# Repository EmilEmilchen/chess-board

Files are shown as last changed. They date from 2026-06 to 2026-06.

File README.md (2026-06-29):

# Digital RFID-reading Chess Board

## BOMs
BOM files from suppliers are in their respective directories, DigiKey is strongly preferred, LCSC part numbers of equal or equivalent parts are given in the KiCad Symbol Table (aka. KiCad BOM) in case of using JLCPCB assembly services later.
The KiCad generated BOM file is in the root (BOM.csv).
Here is a [link to the BOM on the DigiKey website](https://www.digikey.de/de/mylists/list/6JU4LPDGX9).
Note that 4 (2x2) connectors are to be ordered from amazon or eBay since thats not only cheaper but also simpler (these are still referenced in the DigiKey BOM but not connected to any DigiKey part, same goes for the MFRC522 RFID main IC, that's about 5-10x cheaper when ordered from AliExpress (around 0.47€/pcs).
The materials in the BOM are for one sub-board (2x2 matrix of RFID readers) with a slight excess in some cases where it was cheaper to order e.g. 10 pcs instead of 8 due to bulk discounts.

### Note
The entire chess board will be made up of 16x the same 2x2 matrix circuit (around 80 USD total expected cost).

## KiCad
Use KiCad Version 10 or newer to open the .kicad_pro file, libraries are in the libs/ folder and should automatically be used.

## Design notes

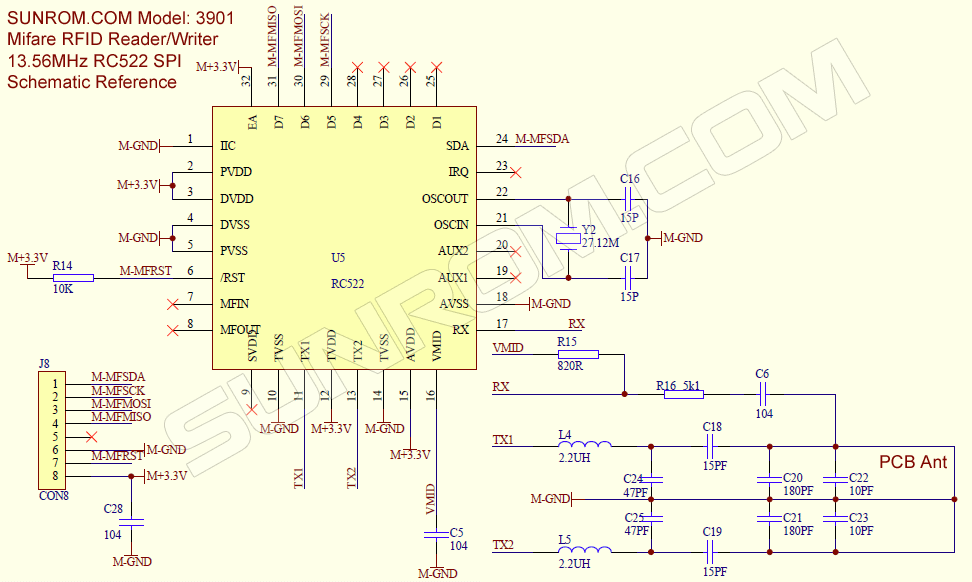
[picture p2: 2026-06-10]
Reference/Reader schematic.png

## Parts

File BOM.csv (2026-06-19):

Reference | Qty | Value | DNP | Exclude from BOM | Exclude from Board | Footprint | Datasheet | Manufacturer | LCSC Part | Description | DigiKey PN | DigiKey URL | Note
C1,C2,C7,C8,C18,C19,C22,C23,C32,C33,C36,C37,C46,C47,C50,C51 | 16 | 15pF NP0 |  |  |  | Capacitor_SMD:C_0603_1608Metric |  |  | C1645 | Unpolarized capacitor, small symbol | 1276-1296-2-ND | https://www.digikey.de/de/products/detail/samsung-electro-mechanics/CL10C150JB8NNNC/3886954
C3,C6,C13,C15,C17,C24,C29,C31,C38,C43,C45,C52,C57,C58,C59,C60,C61,C62,C63,C64,C65 | 21 | 100nF |  |  |  | Capacitor_SMD:C_0603_1608Metric |  |  | C14663 | Unpolarized capacitor, small symbol | 1276-1000-2-ND | https://www.digikey.de/de/products/detail/samsung-electro-mechanics/CL10B104KB8NNNC/3886658
C4,C5,C20,C21,C34,C35,C48,C49 | 8 | 47pF NP0 |  |  |  | Capacitor_SMD:C_0603_1608Metric |  |  | C1665 | Unpolarized capacitor, small symbol | 1276-1037-2-ND | https://www.digikey.de/de/products/detail/samsung-electro-mechanics/CL10C470JB8NNNC/3886695
C9,C11,C25,C26,C39,C40,C53,C54 | 8 | 180pF NP0 |  |  |  | Capacitor_SMD:C_0603_1608Metric |  |  | C1683 | Unpolarized capacitor, small symbol | 490-1433-2-ND | https://www.digikey.de/de/products/detail/murata-electronics/GRM1885C1H181JA01D/586959
C10,C12,C27,C28,C41,C42,C55,C56 | 8 | 10pF NP0 |  |  |  | Capacitor_SMD:C_0603_1608Metric |  |  | C1640 | Unpolarized capacitor, small symbol | 1276-1027-2-ND | https://www.digikey.de/de/products/detail/samsung-electro-mechanics/CL10C100JB8NNNC/3886685
C66,C67,C68,C69 | 4 | 1uF |  |  |  | Capacitor_SMD:C_0603_1608Metric |  |  | C15849 | Unpolarized capacitor, small symbol | 1276-1860-2-ND | https://www.digikey.de/de/products/detail/samsung-electro-mechanics/CL10A105KB8NNNC/3887518
J1,J3 | 2 | IN |  |  |  | Connector_PinSocket_2.54mm:PinSocket_1x10_P2.54mm_Horizontal |  |  |  | Generic connector, single row, 01x10, script generated (kicad-library-utils/schlib/autogen/connector/) |  |  | Generic
J2,J4 | 2 | OUT |  |  |  | Connector_PinSocket_2.54mm:PinSocket_1x10_P2.54mm_Horizontal |  |  |  | Generic connector, single row, 01x10, script generated (kicad-library-utils/schlib/autogen/connector/) |  |  | Generic
L1,L2,L3,L4,L5,L6,L7,L8 | 8 | 2.2UH |  |  |  | Inductor_SMD:L_0603_1608Metric |  |  | C531282 | Inductor, small symbol | 445-6754-2-ND | https://www.digikey.de/de/products/detail/tdk/MLZ1608N2R2LT000/2523492
R1,R5,R8,R11 | 4 | 820R |  |  |  | Resistor_SMD:R_0603_1608Metric |  |  | C23179 | Resistor, small symbol | 311-820HRTR-ND | https://www.digikey.de/de/products/detail/yageo/RC0603FR-07820RL/727403
R2,R6,R9,R12 | 4 | 5k1 |  |  |  | Resistor_SMD:R_0603_1608Metric |  |  | C23186 | Resistor, small symbol | 311-5.10KHRTR-ND | https://www.digikey.de/de/products/detail/yageo/RC0603FR-075K1L/727268
R3,R4,R7,R10,R13,R14,R15,R16 | 8 | 10k |  |  |  | Resistor_SMD:R_0603_1608Metric |  |  | C25804 | Resistor, small symbol | 311-10.0KHRTR-ND | https://www.digikey.de/de/products/detail/yageo/RC0603FR-0710KL/726880
U1,U3,U4,U5 | 4 | MFRC52202HN1,151 |  |  |  | EasyEDA:QFN-32_L5.0-W5.0-P0.50-BL-EP3.4 | https://lcsc.com/product-detail/RF-Transceiver-ICs_NXP_MFRC52202HN1-151_MFRC52202HN1-151_C11322.html | NXP(恩智浦) | C11322 |  |  |  | Aliexpress
U2 | 1 | SN74HC595N |  |  |  | EasyEDA:DIP-16_L19.8-W6.5-P2.54-LS7.6-BL | https://lcsc.com/product-detail/74-Series_TI_SN74HC595N_SN74HC595N_C78711.html | TI(德州仪器) | C78711 |  | 296-1600-5-ND | https://www.digikey.de/de/products/detail/texas-instruments/SN74HC595N/277246
Y1,Y2,Y3,Y4 | 4 | 27.12 MHz Crystal |  |  |  | Crystal:Crystal_SMD_3225-4Pin_3.2x2.5mm |  |  | C29975 | Four pin crystal, GND on pins 2 and 4, small symbol | 2151-RH100-27.120-10-F-1010-TR-ND | https://www.digikey.de/de/products/detail/raltron-electronics/RH100-27-120-10-F-1010-TR/13151016

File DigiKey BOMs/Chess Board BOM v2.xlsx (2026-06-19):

Das Herkunftsland kann sich zum Zeitpunkt des Versands geändert haben.
Die angezeigten HTSUS- und ECCN-Informationen dienen nur zu Informationszwecken und stellen keine Zusicherung oder Garantie für die Richtigkeit oder Zuverlässigkeit dieser Klassifizierungen dar. Alle Informationen werden ohne Gewähr zur Verfügung gestellt und können ohne vorherige Ankündigung geändert werden. Jede Verwendung der bereitgestellten Informationen erfolgt ohne Rechtsansprüche an Digi-Key und auf Risiko des Benutzers.
Index | Hersteller-Teilenummer | Herstellername | Beschreibung | Lieferzeit | Verfügbarkeit | Lagerstatus | Verlust % | Gewünschte Menge 1 | Packungsmenge 1 | Packungstyp 1 | Digi-Key-Teilenr. 1 | Stückpreis 1 | Gesamtpreis 1 | Mindestbestellmenge 1 | Kundenreferenz | Gewünschte Teilenummer | Lieferzeit in Wochen | Datenblatt | Referenzbezeichner | US-Einfuhrzoll | Hinweis | Status der Komponente | RoHS-Status | REACH-Status | Feuchteempfindlichkeit (MSL) | ECCN | HTSUS | Herkunftsland | Informationen zur Umweltverträglichkeit | Original-Teilenummern | Maßeinheit | Abbildung | Produkthinweise
1 | CL10C150JB8NNNC | Samsung Electro-Mechanics | CAP CER 15PF 50V C0G/NP0 0603 |  | 58.491 | Artikel auf Lager |  | 16 | 16 | Cut Tape (CT) | 1276-1296-1-ND | 0,03800 | 0,61 $ | 1 | 15pF NP0 | 1276-1296-2-ND | 31 | https://weblib.samsungsem.com/mlcc/mlcc-ec-data-sheet.do?partNumber=CL10C150JB8NNN | C1,C2,C7,C8,C18,C19,C22,C23,C32,C33,C36,C37,C46,C47,C50,C51 | N/A |  | Aktiv | RoHS3-konform | Von REACH nicht betroffen | 1 (Unbegrenzt) | EAR99 | 8532.24.0020 | Philippines | https://www.samsungsem.com/files/fileDown.do?key=ed1dfdfa-645e-4252-b707-17f9b1502dd1|https://www.samsungsem.com/global/support/certificate/product-stewardship.do | 1276-1296-2-ND | Each | https://mm.digikey.com/Volume0/opasdata/d220001/medias/images/2537/Ceramic-Capacitor-CL-Series.jpg
2 | CL10B104KB8NNNC | Samsung Electro-Mechanics | CAP CER 0.1UF 50V X7R 0603 |  | 6.517.749 | Artikel auf Lager |  | 21 | 21 | Cut Tape (CT) | 1276-1000-1-ND | 0,02700 | 0,57 $ | 1 | 100nF | 1276-1000-2-ND | 31 | https://mm.digikey.com/Volume0/opasdata/d220001/medias/docus/609/CL10B104KB8NNNC_Spec.pdf | C3,C6,C13,C15,C17,C24,C29,C31,C38,C43,C45,C52,C57,C58,C59,C60,C61,C62,C63,C64,C65 | N/A |  | Aktiv | RoHS3-konform | Von REACH nicht betroffen | 1 (Unbegrenzt) | EAR99 | 8532.24.0020 | Philippines | https://www.samsungsem.com/files/fileDown.do?key=ed1dfdfa-645e-4252-b707-17f9b1502dd1|https://www.samsungsem.com/global/support/certificate/product-stewardship.do | 1276-1000-2-ND | Each | https://mm.digikey.com/Volume0/opasdata/d220001/medias/images/2537/Ceramic-Capacitor-CL-Series.jpg
3 | CL10C470JB8NNNC | Samsung Electro-Mechanics | CAP CER 47PF 50V C0G/NP0 0603 |  | 1.515.314 | Artikel auf Lager |  | 10 | 10 | Cut Tape (CT) | 1276-1037-1-ND | 0,03600 | 0,36 $ | 1 | 47pF NP0 | 1276-1037-2-ND | 31 | https://mm.digikey.com/Volume0/opasdata/d220001/medias/docus/609/CL10C470JB8NNNC_Spec.pdf | C4,C5,C20,C21,C34,C35,C48,C49 | N/A |  | Aktiv | RoHS3-konform | Von REACH nicht betroffen | 1 (Unbegrenzt) | EAR99 | 8532.24.0020 | China | https://www.samsungsem.com/files/fileDown.do?key=ed1dfdfa-645e-4252-b707-17f9b1502dd1|https://www.samsungsem.com/global/support/certificate/product-stewardship.do | 1276-1037-2-ND | Each | https://mm.digikey.com/Volume0/opasdata/d220001/medias/images/2537/Ceramic-Capacitor-CL-Series.jpg
4 | GRM1885C1H181JA01D | Murata Electronics | CAP CER 180PF 50V C0G/NP0 0603 |  | 33.152 | Artikel auf Lager |  | 10 | 10 | Cut Tape (CT) | 490-1433-1-ND | 0,07700 | 0,77 $ | 1 | 180pF NP0 | 490-1433-2-ND | 17 | https://search.murata.co.jp/Ceramy/image/img/A01X/G101/ENG/GRM1885C1H181JA01-01.pdf | C9,C11,C25,C26,C39,C40,C53,C54 | N/A |  | Nicht für neue Designs | RoHS3-konform | Von REACH nicht betroffen | 1 (Unbegrenzt) | EAR99 | 8532.24.0020 | Japan |  | 490-1433-2-ND | Each | https://mm.digikey.com/Volume0/opasdata/d220001/medias/images/5447/490-Ceramic-Capacitor-Tan-Field.jpg
5 | CL10C100JB8NNNC | Samsung Electro-Mechanics | CAP CER 10PF 50V C0G/NP0 0603 |  | 216.308 | Artikel auf Lager |  | 10 | 10 | Cut Tape (CT) | 1276-1027-1-ND | 0,03100 | 0,31 $ | 1 | 10pF NP0 | 1276-1027-2-ND | 31 | https://mm.digikey.com/Volume0/opasdata/d220001/medias/docus/609/CL10C100JB8NNNC_Spec.pdf | C10,C12,C27,C28,C41,C42,C55,C56 | N/A |  | Aktiv | RoHS3-konform | Von REACH nicht betroffen | 1 (Unbegrenzt) | EAR99 | 8532.24.0020 | Philippines | https://www.samsungsem.com/files/fileDown.do?key=ed1dfdfa-645e-4252-b707-17f9b1502dd1|https://www.samsungsem.com/global/support/certificate/product-stewardship.do | 1276-1027-2-ND | Each | https://mm.digikey.com/Volume0/opasdata/d220001/medias/images/2537/Ceramic-Capacitor-CL-Series.jpg
6 | CL10A105KB8NNNC | Samsung Electro-Mechanics | CAP CER 1UF 50V X5R 0603 |  | 1.684.864 | Artikel auf Lager |  | 4 | 4 | Cut Tape (CT) | 1276-1860-1-ND | 0,11000 | 0,44 $ | 1 | 1uF | 1276-1860-2-ND | 31 | https://mm.digikey.com/Volume0/opasdata/d220001/medias/docus/658/CL10A105KB8NNNC_Spec.pdf | C66,C67,C68,C69 | N/A |  | Aktiv | RoHS3-konform | Von REACH nicht betroffen | 1 (Unbegrenzt) | EAR99 | 8532.24.0020 | Philippines | https://www.samsungsem.com/files/fileDown.do?key=ed1dfdfa-645e-4252-b707-17f9b1502dd1|https://www.samsungsem.com/global/support/certificate/product-stewardship.do | 1276-1860-2-ND | Each | https://mm.digikey.com/Volume0/opasdata/d220001/medias/images/2537/Ceramic-Capacitor-CL-Series.jpg
7 | MLZ1608N2R2LT000 | TDK | FIXED IND 2.2UH 500MA 180 MOHM |  | 35.693 | Artikel auf Lager |  | 10 | 10 | Cut Tape (CT) | 445-6754-1-ND | 0,08800 | 0,88 $ | 1 | 2.2UH | 445-6754-2-ND | 15 | https://product.tdk.com/en/system/files | L1,L2,L3,L4,L5,L6,L7,L8 | N/A |  | Aktiv | RoHS3-konform | Von REACH nicht betroffen | 1 (Unbegrenzt) | EAR99 | 8504.50.4000 | Japan | https://product.tdk.com/en/environment/index.html | 445-6754-2-ND | Each | https://mm.digikey.com/Volume0/opasdata/d220001/medias/images/632/0603-MLZ.jpg
8 | RC0603FR-07820RL | YAGEO | RES 820 OHM 1% 1/10W 0603 |  | 14 | Artikel auf Lager |  | 10 | 10 | Cut Tape (CT) | 311-820HRCT-ND | 0,02500 | 0,25 $ | 1 | 820R | 311-820HRTR-ND | 17 | https://yageogroup.com/content/datasheet/asset/file/PYU-RC_GROUP_51_ROHS_L | R1,R5,R8,R11 | N/A |  | Aktiv | RoHS3-konform | Von REACH nicht betroffen | 1 (Unbegrenzt) | EAR99 | 8533.21.0030 | Taiwan | https://www.yageogroup.com/content/Resource%20Library/Product%20Environmental%20Compliance/RoHS_Compliance_YAGEO.pdf | 311-820HRTR-ND | Each | https://mm.digikey.com/Volume0/opasdata/d220001/derivates/6/100/962/238/13_0603-%281608-metric%29_web%28640x640%29.jpg
9 | RC0603FR-075K1L | YAGEO | RES 5.1K OHM 1% 1/10W 0603 |  | 746.977 | Artikel auf Lager |  | 10 | 10 | Cut Tape (CT) | 311-5.10KHRCT-ND | 0,02500 | 0,25 $ | 1 | 5k1 | 311-5.10KHRTR-ND | 17 | https://yageogroup.com/content/datasheet/asset/file/PYU-RC_GROUP_51_ROHS_L | R2,R6,R9,R12 | N/A |  | Aktiv | RoHS3-konform | Von REACH nicht betroffen | 1 (Unbegrenzt) | EAR99 | 8533.21.0030 | Taiwan | https://www.yageogroup.com/content/Resource%20Library/Product%20Environmental%20Compliance/RoHS_Compliance_YAGEO.pdf | 311-5.10KHRTR-ND | Each | https://mm.digikey.com/Volume0/opasdata/d220001/derivates/6/003/121/213/cut-tape-render_web%28640x640%29.jpg
10 | RC0603FR-0710KL | YAGEO | RES 10K OHM 1% 1/10W 0603 |  | 11.782.808 | Artikel auf Lager |  | 10 | 10 | Cut Tape (CT) | 311-10.0KHRCT-ND | 0,02500 | 0,25 $ | 1 | 10k | 311-10.0KHRTR-ND | 17 | https://yageogroup.com/content/datasheet/asset/file/PYU-RC_GROUP_51_ROHS_L | R3,R4,R7,R10,R13,R14,R15,R16 | N/A |  | Aktiv | RoHS3-konform | Von REACH nicht betroffen | 1 (Unbegrenzt) | EAR99 | 8533.21.0030 | Taiwan | https://www.yageogroup.com/content/Resource%20Library/Product%20Environmental%20Compliance/RoHS_Compliance_YAGEO.pdf | 311-10.0KHRTR-ND | Each | https://mm.digikey.com/Volume0/opasdata/d220001/derivates/6/003/121/213/cut-tape-render_web%28640x640%29.jpg
11 | SN74HC595N | Texas Instruments | IC SR TRI-STATE 8BIT 16-PDIP |  | 4.821 | Artikel auf Lager |  | 1 | 1 | Tube | 296-1600-5-ND | 1,79000 | 1,79 $ | 1 | SN74HC595N | 296-1600-5-ND | 6 | https://www.ti.com/general/docs/suppproductinfo.tsp?distId=10 | U2 | N/A |  | Aktiv | RoHS3-konform | Von REACH nicht betroffen | Nicht anwendbar | EAR99 | 8542.39.0070 | United States |  | 296-1600-5-ND | Each | https://mm.digikey.com/Volume0/opasdata/d220001/medias/images/4015/296%7E4040049%7EN%7E16.jpg
12 | RH100-27.120-10-F-1010-TR | Raltron Electronics | CRYSTAL 27.1200MHZ 10PF SMD |  | 1.176 | Artikel auf Lager |  | 4 | 4 | Cut Tape (CT) | 2151-RH100-27.120-10-F-1010-TRCT-ND | 0,18000 | 0,72 $ | 1 | 27.12 MHz Crystal | 2151-RH100-27.120-10-F-1010-TR-ND | 12 | https://www.raltron.com/webproducts/specs/CRYSTAL/RH100-27.120-10-F-1010-TR.pdf | Y1,Y2,Y3,Y4 | N/A |  | Aktiv | RoHS3-konform | Von REACH nicht betroffen | 1 (Unbegrenzt) | EAR99 | 8541.60.0060 | China | https://www.raltron.com/webproducts/technical/REACH.pdf|https://www.raltron.com/webproducts/rohs/RoHS-Policy.pdf|https://mm.digikey.com/Volume0/opasdata/d220001/medias/docus/8938/Rami%20Technology%20CA%20Prop%2065%20Statement.pdf | 2151-RH100-27.120-10-F-1010-TR-ND | Each | https://mm.digikey.com/Volume0/opasdata/d220001/derivates/6/100/967/023/MFG_2151_RH100_web%28640x640%29.jpg
13 |  |  |  |  |  |  |  | 4 |  |  |  |  |  |  | MFRC52202HN1,151 | MFRC52202HN1,151-AliExpress | N/A |  | U1,U3,U4,U5 |  | from AliExpress (way cheaper) |  | - | - |  | - | - | - |  | MFRC52202HN1,151-AliExpress |  |  | Für diesen Eintrag kann kein Angebot erstellt werden, da das Produkt nicht von Digi-Key geführt wird..
14 |  |  |  |  |  |  |  | 2 |  |  |  |  |  |  | IN | INPUT | N/A |  | J1,J3 |  | from e.g. Amazon, easier AND cheaper |  | - | - |  | - | - | - |  | INPUT |  |  | Für diesen Eintrag kann kein Angebot erstellt werden, da das Produkt nicht von Digi-Key geführt wird..
15 |  |  |  |  |  |  |  | 2 |  |  |  |  |  |  | OUT | OUTPUT | N/A |  | J2,J4 |  | from e.g. Amazon, easier AND cheaper |  | - | - |  | - | - | - |  | OUTPUT |  |  | Für diesen Eintrag kann kein Angebot erstellt werden, da das Produkt nicht von Digi-Key geführt wird..

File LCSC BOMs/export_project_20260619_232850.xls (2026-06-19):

BOM.csv |  |  |  |  |  |  |  |  |  | LCSC BOM Quotation
 |  |  |  |  |  |  |  |  |  | BOM Date Created：19/06/26 23:24:45 |  |  |  | BOM Export Date: 19/06/26 23:28:50 |  |  |  | The matching result is a real-time query result, availability and prices may fluctuate. Backorder items are estimated prices for your reference, please submit "Create Quote" to get the real price. All information is provided "as is" and is subject to change without notice. Any use made of the information provided is without recourse to LCSC and at the user's risk.
 |  |  |  |  |  |  |  |  |  | EST TOTAL :$8.18 |  |  |  | Website：https://www.lcsc.com/bom | https://www.lcsc.com/bom | https://www.lcsc.com/bom | https://www.lcsc.com/bom
Uploaded data |  |  |  |  |  |  |  |  |  | LCSC Matching Results
LCSC# | Mfr. | Mrf# | Description | Package | Value | Customer Part Number | Quantity | Target Price(EUR) | Target Lead Time(Business Days) | Mrf# | Mfr. | Order Qty. | Unit Price(EUR) | Ext.Price(EUR) | LCSC# | Package | Min | Mult | SPQ | Availability | Stock Status | Customer Notes | Description | Matched status | Product Link
 |  |  | 15pF NP0 | Capacitor_SMD:C_0603_1608Metric |  | C1,C2,C7,C8,C18,C19,C22,C23,C32,C33,C36,C37,C46,C47,C50,C51 | 16 |  |  | CC0603JRNPO9BN150 | YAGEO | 100 | 0.0041 | 0.41 | C107037 | 0603 | 100 | 100 | 4000 | 779400 | In Stock |  | 15pF ±5% 50V Ceramic Capacitor NP0 0603 | Partial Matches | https://www.lcsc.com/product-detail/C107037.html
 |  |  | 100nF | Capacitor_SMD:C_0603_1608Metric |  | C3,C13,C15,C17,C29,C31,C43,C45,C57,C58,C59,C60,C61,C62,C63,C64,C | 17 |  |  | CL10B104KB8NNNC | Samsung Electro-Mechanics | 100 | 0.0102 | 1.02 | C1591 | 0603 | 100 | 100 | 4000 | 4000 | In Stock |  | 100nF ±10% 50V Ceramic Capacitor X7R 0603 | Partial Matches | https://www.lcsc.com/product-detail/C1591.html
 |  |  | 47pF NP0 | Capacitor_SMD:C_0603_1608Metric |  | C4,C5,C20,C21,C34,C35,C48,C49 | 8 |  |  | CC0603JRNPO9BN470 | YAGEO | 100 | 0.0050 | 0.50 | C105622 | 0603 | 100 | 100 | 4000 | 248100 | In Stock |  | 47pF ±5% 50V Ceramic Capacitor NP0 0603 | Partial Matches | https://www.lcsc.com/product-detail/C105622.html
 |  |  | 100nF NP0 | Capacitor_SMD:C_0603_1608Metric |  | C6,C24,C38,C52 | 4 |  |  | CL10B104KB8NNNC | Samsung Electro-Mechanics | 100 | 0.0102 | 1.02 | C1591 | 0603 | 100 | 100 | 4000 | 4000 | In Stock |  | 100nF ±10% 50V Ceramic Capacitor X7R 0603 | Partial Matches | https://www.lcsc.com/product-detail/C1591.html
 |  |  | 180pF NP0 | Capacitor_SMD:C_0603_1608Metric |  | C9,C11,C25,C26,C39,C40,C53,C54 | 8 |  |  | CC0603JRNPO9BN181 | YAGEO | 100 | 0.0056 | 0.56 | C107041 | 0603 | 100 | 100 | 4000 | 226400 | In Stock |  | 180pF ±5% 50V Ceramic Capacitor NP0 0603 | Partial Matches | https://www.lcsc.com/product-detail/C107041.html
 |  |  | 10pF NP0 | Capacitor_SMD:C_0603_1608Metric |  | C10,C12,C27,C28,C41,C42,C55,C56 | 8 |  |  | CC0603JRNPO9BN100 | YAGEO | 100 | 0.0042 | 0.42 | C106245 | 0603 | 100 | 100 | 4000 | 1234500 | In Stock |  | 10pF ±5% 50V Ceramic Capacitor NP0 0603 | Partial Matches | https://www.lcsc.com/product-detail/C106245.html
 |  |  | 1uF | Capacitor_SMD:C_0603_1608Metric |  | C66,C67,C68,C69 | 4 |  |  | CL10B105KA8NNNC | Samsung Electro-Mechanics | 50 | 0.0193 | 0.97 | C29936 | 0603 | 50 | 50 | 4000 | 134100 | In Stock |  | 1uF ±10% 25V Ceramic Capacitor X7R 0603 | Partial Matches | https://www.lcsc.com/product-detail/C29936.html
 |  |  | IN1 | Connector_PinSocket_2.54mm:PinSocket_1x10_P2.54mm_Horizontal |  | J1 | 1 |  |  | -(The data has been deleted.) | - | - | - | - | - | - | - | - | - | - | - | - | - | -
 |  |  | OUT1 | Connector_PinSocket_2.54mm:PinSocket_1x10_P2.54mm_Horizontal |  | J2 | 1 |  |  | -(The data has been deleted.) | - | - | - | - | - | - | - | - | - | - | - | - | - | -
 |  |  | IN2 | Connector_PinSocket_2.54mm:PinSocket_1x10_P2.54mm_Horizontal |  | J3 | 1 |  |  | -(The data has been deleted.) | - | - | - | - | - | - | - | - | - | - | - | - | - | -
 |  |  | OUT2 | Connector_PinSocket_2.54mm:PinSocket_1x10_P2.54mm_Horizontal |  | J4 | 1 |  |  | -(The data has been deleted.) | - | - | - | - | - | - | - | - | - | - | - | - | - | -
 |  |  | 2.2UH | Inductor_SMD:L_0603_1608Metric |  | L1,L2,L3,L4,L5,L6,L7,L8 | 8 |  |  | LQM18PN2R2MFRL | muRata | 10 | 0.1034 | 1.03 | C337910 | 0603 | 10 | 10 | 4000 | 17000 | In Stock |  | 750mA 2.2uH ±20% 300mΩ Multilayer inductor 0603 Fixed Inductors RoHS | Partial Matches | https://www.lcsc.com/product-detail/C337910.html
 |  |  | 820R | Resistor_SMD:R_0603_1608Metric |  | R1,R5,R8,R11 | 4 |  |  | RC0603FR-07820RL | YAGEO | 100 | 0.0017 | 0.17 | C114638 | 0603 | 100 | 100 | 5000 | 74000 | In Stock |  | 100mW 820Ω 75V Thick Film Resistor ±100ppm/℃ ±1% 0603 Chip Resistor - Surface Mount RoHS | Partial Matches | https://www.lcsc.com/product-detail/C114638.html
 |  |  | 5k1 | Resistor_SMD:R_0603_1608Metric |  | R2,R6,R9,R12 | 4 |  |  | FRC0603F5101TS | FOJAN | 100 | 0.0020 | 0.20 | C2907044 | 0603 | 100 | 100 | 5000 | 7523800 | In Stock |  | 5.1kΩ ±1% 100mW 0603 Thick Film Resistor | Partial Matches | https://www.lcsc.com/product-detail/C2907044.html
 |  |  | 10K | Resistor_SMD:R_0603_1608Metric |  | R3,R4,R7,R10 | 4 |  |  | FRC0603J103 TS | FOJAN | 100 | 0.0013 | 0.13 | C2930027 | 0603 | 100 | 100 | 5000 | 214600 | In Stock |  | 10kΩ ±5% 100mW 0603 Thick Film Resistor | Partial Matches | https://www.lcsc.com/product-detail/C2930027.html
 |  |  | 10k | Resistor_SMD:R_0603_1608Metric |  | R13,R14,R15,R16 | 4 |  |  | FRC0603J103 TS | FOJAN | 100 | 0.0013 | 0.13 | C2930027 | 0603 | 100 | 100 | 5000 | 214600 | In Stock |  | 10kΩ ±5% 100mW 0603 Thick Film Resistor | Partial Matches | https://www.lcsc.com/product-detail/C2930027.html
C11322 | NXP(恩智浦) |  | MFRC52202HN1,151 | EasyEDA:QFN-32_L5.0-W5.0-P0.50-BL-EP3.4 |  | U1,U3,U4,U5 | 4 |  |  | -(The data has been deleted.) | - | - | - | - | - | - | - | - | - | - | - | - | - | -
C78711 | TI(德州仪器) |  | SN74HC595N | EasyEDA:DIP-16_L19.8-W6.5-P2.54-LS7.6-BL |  | U2 | 1 |  |  | SN74HC595N | TI | 1 | 1.1265 | 1.13 | C78711 | DIP-16 | 1 | 1 | 25 | 627 | In Stock |  | 2V~6V 1 6mA 26ns@6V,50pF Serial-to-Serial or Parallel DIP-16 Shift Registers RoHS | Exact Matches | https://www.lcsc.com/product-detail/C78711.html
 |  |  | 27.12 MHz Crystal | Crystal:Crystal_SMD_3225-4Pin_3.2x2.5mm |  | Y1,Y2,Y3,Y4 | 4 |  |  | X32252712MMB4SI | YXC Crystal Oscillators | 5 | 0.0978 | 0.49 | C29975 | SMD3225-4P | 5 | 5 | 3000 | 13375 | In Stock |  | Crystal 27.12MHz ±10ppm 10pF SMD3225-4P | Partial Matches | https://www.lcsc.com/product-detail/C29975.html

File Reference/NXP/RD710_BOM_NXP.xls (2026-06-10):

 |  | RD710-RD852 Bill-Of-Material
ID | Abbrev | Ref Des | Component | Pattern | Value | Manufacturer | Label | RD710 | RD852
2 | C | C01,C02,C10,C11,C12,C13,C14,C15,C16,C17,C18,C19,C25,C26,C27,C30,C31,C32,C37,C44,C48,C49,C50,C51,C54,C56 | capacitor | CAPC0603 | 100n |  |  | 26 | 26
3 | C | C38 | capacitor | CAPC0603 | 100n |  |  |  | 1
4 | C | C39,C55 | capacitor | CAPC0603 | 100n |  |  | 2
5 | C | C28,C29,C46 | capacitor Ta | C_TANTAL_D | 100uF/16V |  |  | 3 | 3
 | C | C43 | capacitor | CAPC0603 | 100p
6 | C | C05,C06,C07,C08 | capacitor | CAPC0603 | 15p |  |  | 4 | 4
7 | C | C34,C52,C53 | capacitor | CAPC0603 | 15p |  |  | 3
8 | C | C03,C04,C20,C21,C22,C23,C24 | capacitor | CAPC0805 | 1uF |  |  | 7 | 7
9 | C | C33 | capacitor | CAPC0805 | 1uF |  |  | 1
10 | C | C36 | capacitor | CAPC0805 | 1uF |  |  |  | 1
14 | C | C42, C45 | capacitor | CAPC0805 | 68p 2% NP0 |  |  | 2 | 2
15 | CON | J03,J08 | connector-header | CON5M_LINE | 1x5 PIN (M) | Neltron | 2211S-40G | 2 | 2
16 | CON | J05 | connector-header | LETV10 | 1x8 PIN (M) | Neltron | 2211S-40G | 1 | 1
17 | CON | J07 | connector-header | CON10M | 2x5 PIN (M) | Neltron | 2213S-80G | 1 | 1
18 | CON | J01 | connector JTAG | CON_EHF-105-01-XX-D-SM | JTAG 2x5 50mil | Samtec | EHF-105-01-L-D-SM | 1 | 1
19 | CON | J06 | connector SIM | SAM_CARD | SIM slot 8 pin | C&K Component | CCM03-3004LFT R102 | 1
 | JMP | JMP1,JMP2 | connector-header | JP3_LINE | 1x3 PIN (M) | Neltron | 2211S-40G | 2 | 2
20 | CON | J02 | connector USB | CON_USB_B_THT | USB_B_THT | Tyco | 292304-1 | 1 | 1
21 | D | D03,D12 | diode | SOT-23-5L | ESD quad | ST | ESDA6V1SC5 | 2 | 2
22 | D | D16 | diode | SOT-457 | USB protection | NXP | IP4220CZ6 | 1 | 1
23 | D | D02,D06,D07 | diode | SOT-23 |  |  | BAS16 | 3 | 3
24 | IC | IC05 | IC | SOT-223-4 | LDO regulator | National | LP3961EMP-3.3 | 1 | 1
25 | IC | IC15 | IC | TSOP-6 | MOSFET P-CH 20V 4A | IR | SI3443DV | 1
26 | IC | IC06 | IC | HVQFN32 | reader | NXP | MFRC523 | 1
27 | IC | IC07 | IC | HLQFN48R | reader+SAM | NXP | MFRX852 |  | 1
28 | IC | IC04 | IC | TSSOP-16 | RS232 driver | Sipex | SP3232EBCY | 1 | 1
29 | IC | IC03 | IC | SOIC-8 | RS485 driver | Sipex | SP3485CN-L | 1 | 1
30 | IC | IC10 | IC | SOIC-8 | RS485 driver | Sipex | SP3485CN-L
 | IC | IC11 | IC | TSSOP-6 | high speed MOSFET driver | Intersil | ISL55110IVZ | 1 | 1
31 | IC | IC08,IC09 | IC | SSOP5-0.95 | SPST switch | TI | TS5A3166DBV | 2
 | IC | IC12 | IC | SSOP5-0.95 | SPST switch | TI | TS5A3166DBV | 1 | 1
32 | IC | IC01 | IC | LQFP100 | uC Cortex-M3 | NXP | LPC1768FBD100 | 1 | 1
33 | IC | IC02 | IC | SOT143B | voltage monit. | Maxim | MAX811TEUS+T | 1 | 1
35 | L | L01 | inductor | INDC1812 | 0.1uH | Bourns | PM1812-R10K-RC | 1 | 1
36 | L | L06,L08 | inductor | INDC1812 | 1uH | Panasonic | ELJ-FB1R0KF | 2 | 2
38 | L | L07 | inductor | INDC0805 | 1.5uH | Murata | LQM21NN1R5K10D | 1 | 1
39 | L | L02 | inductor | INDC0805 | 22nH | Murata | LQW2BHN22NJ03L | 1
40 | L | L04 | inductor | INDC0805 | 22nH | Murata | LQW2BHN22NJ03L |  | 1
41 | LD | LD06 | LED | LEDY0805 | green |  | LGR971Z | 1 | 1
42 | LD | LD05 | LED | LEDY0805 | red |  | LHR974Z | 1 | 1
43 | LD | LD01,LD02,LD03,LD04 | LED | LEDY0805 | yellow |  | LYR971-Z | 4 | 4
44 | PU | PUSH1 | push button | SMD 6x6 |  |  | DTSM-62R-B | 1 | 1
46 | Q | T1,T2,T3,T4,T5,T6 | transistor | SOT-23 |  |  | BC817 | 6 | 6
47 | Q | T7 | transistor | SOT-23 |  |  | BC807 | 1 | 1
48 | R | R30,R33,R38,R98 | resistor | RESC0603 | 0R |  |  | 4 | 4
49 | R | R79 | resistor | RESC0603 | 0R |  |  | 1
50 | R | R80 | resistor | RESC0603 | 0R |  |  |  | 1
51 | R | R9,R20,R36,R81,R82 | resistor | RESC0603 | 0R
52 | R | R92 | resistor | RESC0805 | 0R |  |  | 1 | 1
53 | R | R93,R95,R96 | resistor | RESC1206 | 0R |  |  | 3 | 3
 | R | R92,R97 | resistor | RESC1206 | 0R
54 | R | R01,R02,R03,R04,R21,R22,R23,R24,R25,R26,R27,R28,R31,R34,R35,R43,R53,R59,R61,R70,R75,R76,R77,R78,R91,R100 | resistor | RESC0603 | 10K |  |  | 26 | 26
55 | R | R60,R62,R63,R64,R69 | resistor | RESC0603 | 10K |  |  | 5
56 | R | R65,R66,R67,R68,R72,R99 | resistor | RESC0603 | 10K
57 | R | R13,R15,R47,R85,R86 | resistor | RESC1206 | 10R |  |  | 5 | 5
 | R | R94 | resistor | RESC1206 | 100R
58 | R | R14,R87 | resistor | RESC0603 | 120R
60 | R | R41,R42,R56,R57,R88 | resistor | RESC0603 | 1K |  |  | 5 | 5
61 | R | R07,R08 | resistor | RESC0603 | 1K5
62 | R | R19,R37,R54,R55,R58,R89,R90 | resistor | RESC0603 | 1K5 |  |  | 7 | 7
63 | R | R46,R50 | resistor | RESC0603 | 22R |  |  | 2
64 | R | R48,R51,R52 | resistor | RESC0603 | 22R |  |  |  | 3
65 | R | R39 | resistor | RESC0805 | 2K7
66 | R | R40 | resistor | RESC0603 | 2K7 |  |  | 1
67 | R | R10,R11 | resistor | RESC0603 | 33R |  |  | 2 | 2
68 | R | R06,R17,R18,R74,R45 | resistor | RESC0603 | 470R |  |  | 5 | 5
69 | R | R29,R32 | resistor | RESC0603 | 47K |  |  | 2 | 2
70 | R | R05 | resistor | RESC0603 | 4K7 |  |  | 1 | 1
71 | R | R12,R16,R73 | resistor | RESC0603 | 560R |  |  | 3 | 3
72 | R | R83,R84 | resistor | RESC0603 | 560R
73 | R | R44 | resistor | RESC0603 | 820R |  |  | 1
74 | SP | SP1 | beeper | R7,6 | 5V beeper | Digisound | TCW-05 | 1 | 1
75 | SW | SW1 | DIP SW | DIP8_50MIL | DIP switch 8 pos | Tyco | GDH08S04 | 1 | 1
76 | X1 | X1 | oscillator | JO53 | ?
77 | XPCB | PCB | PCB - blue |  |  |  |  | 1 | 1
78 | XT | XT1 | quartz crystal | QUARTZ_ABM3B | 12MHz-B2-T | Abracon | ABM3B-12.000MHZ-B2-T | 1 | 1
79 | XT | XT2 | quartz crystal | QUARTZ_32SMX | 27.12MHz 32SMX-SMI | SMI | Q027120032M10a | 1
 |  |  | TOTAL |  |  |  |  | 172 | 157

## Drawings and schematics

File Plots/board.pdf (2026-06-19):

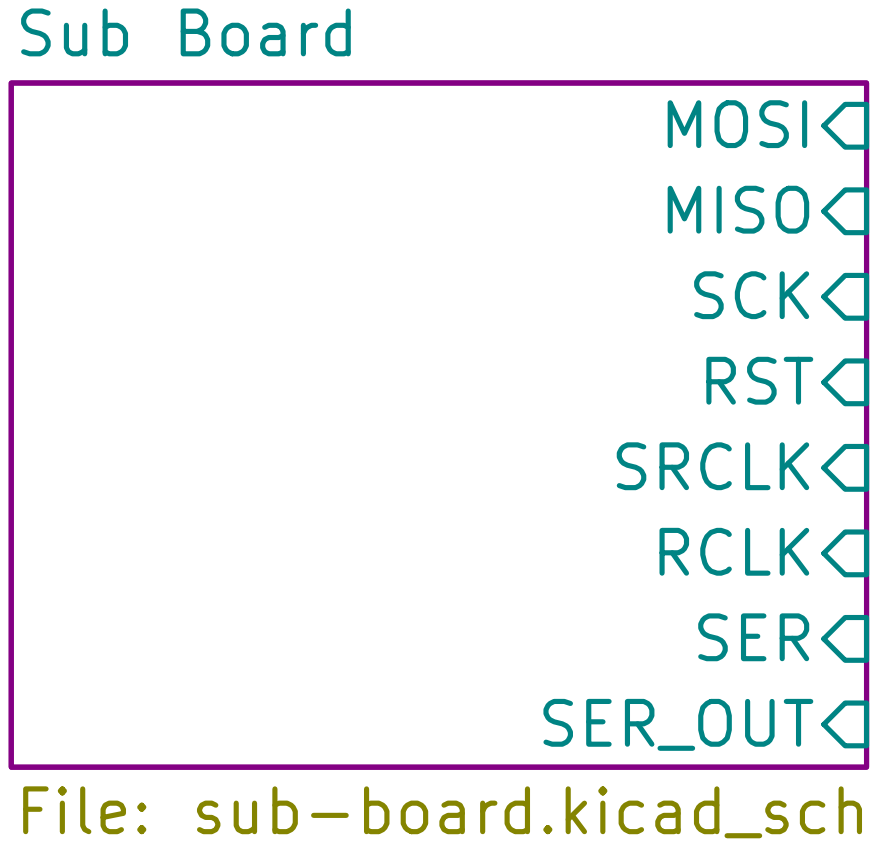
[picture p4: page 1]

Size: A4 | Rev:
KiCad E.D.A. 10.0.3 | Id: 1/6

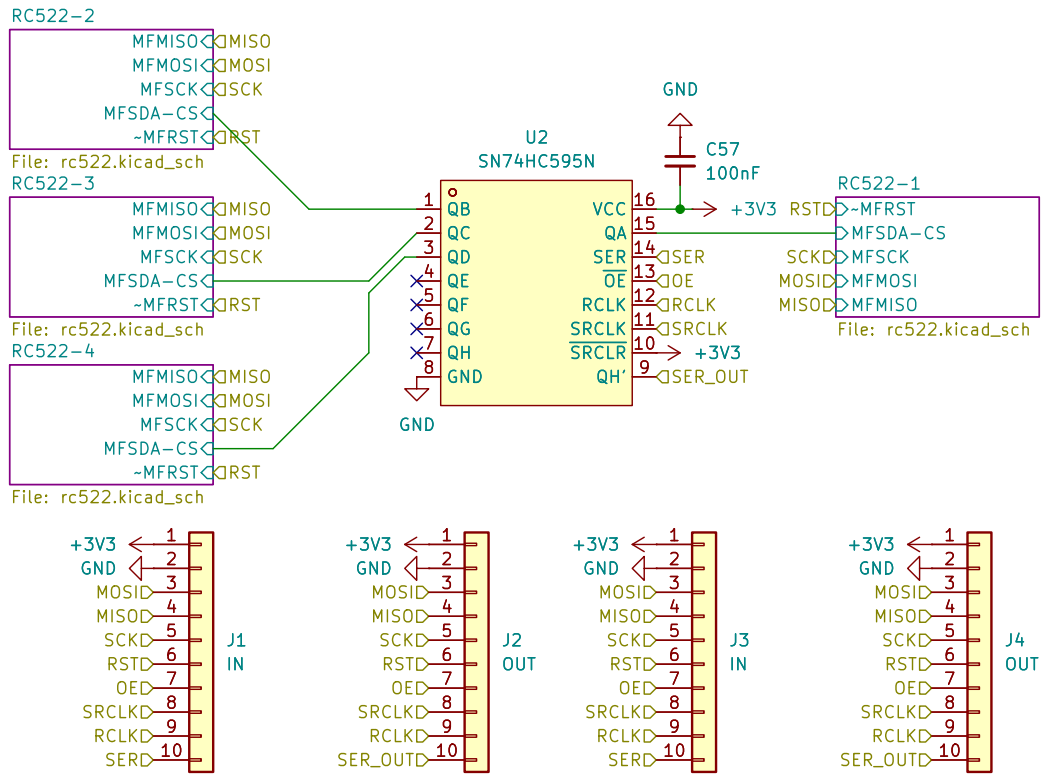
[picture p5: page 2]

~MFRST MFSDA-CS RC522-2
File: rc522.kicad_sch MFMISO MFMOSI MFSCK
10 +3V3 GND +3V3 C57
RCLK MISO

SRCLR 10 SRCLK 11 RCLK 12 OE 13 SER 14 QA 15 VCC 16 GND

~MFRST MFSDA-CS RC522-3

SRCLR 10 SRCLK 11 RCLK 12 OE 13 SER 14 QA 15 VCC 16 U2

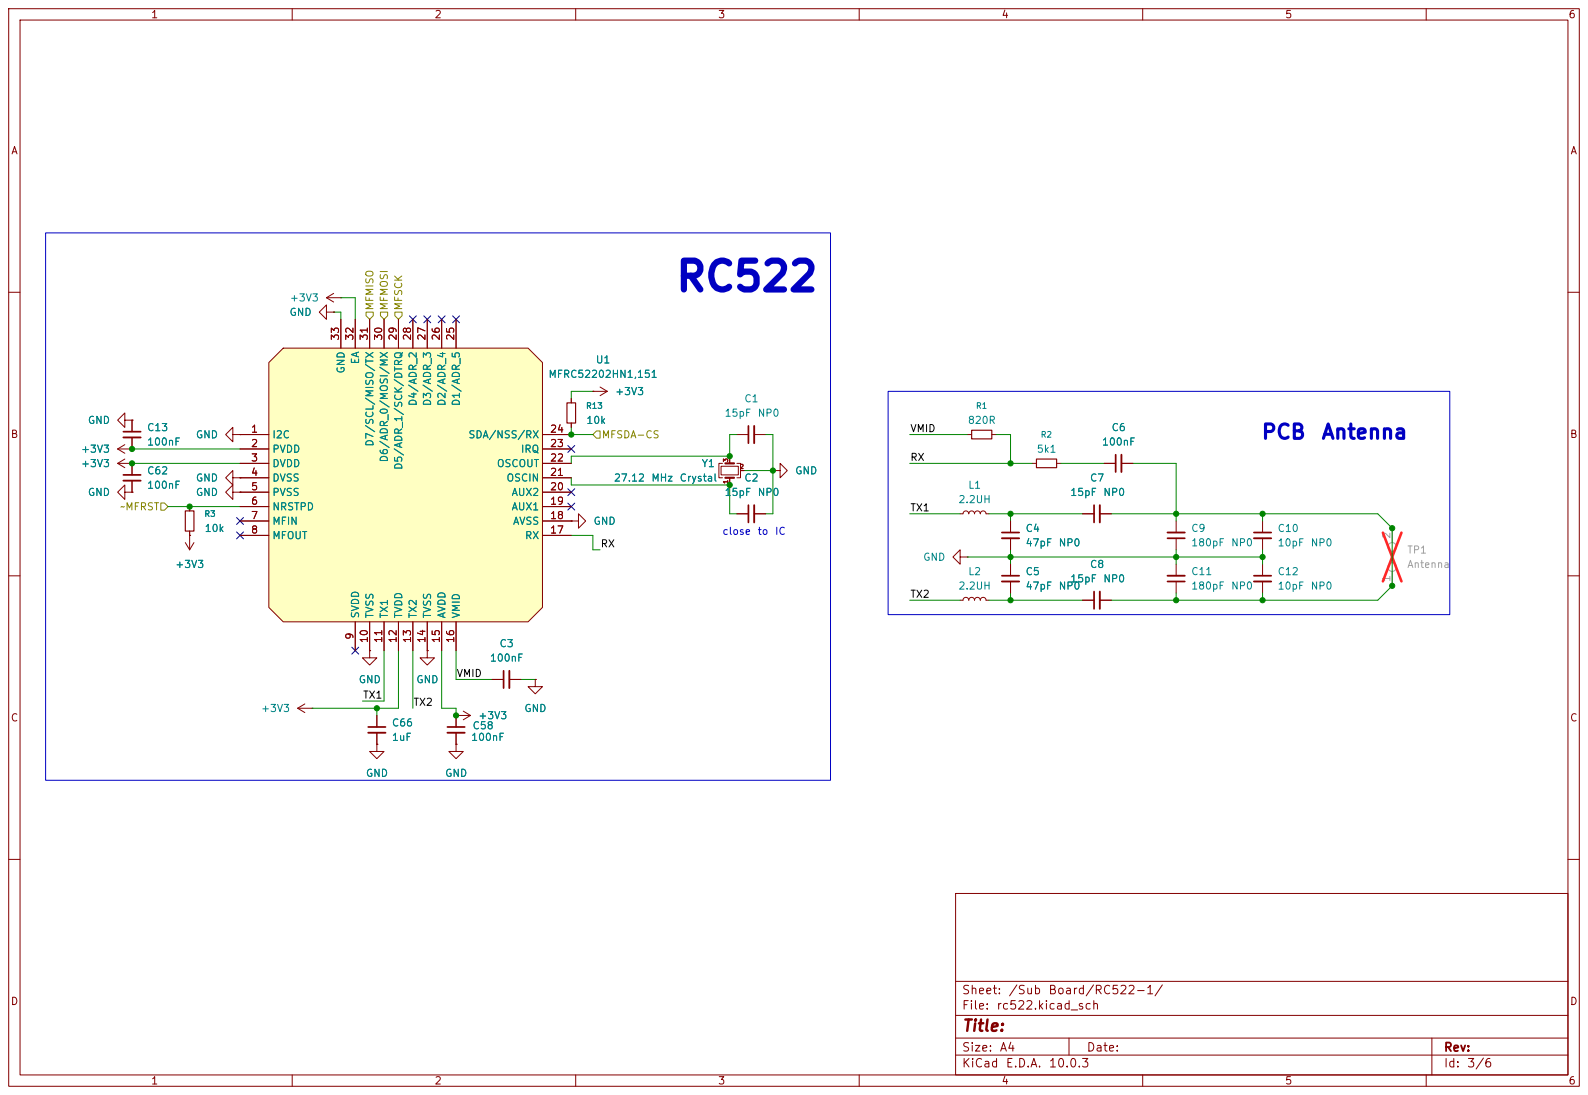
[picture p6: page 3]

9 TVSS 10 TX1 11 TVDD 12 TX2 13 TVSS 14 AVDD 15 VMID 16 RX 17 AVSS 18 AUX1 19 AUX2 20 OSCIN 21 OSCOUT 22 IRQ 23 SDA/NSS/RX 24 D1/ADR_5 25 D2/ADR_4 26 D3/ADR_3 27 D4/ADR_2 28 D5/ADR_1/SCK/DTRQ 29 D6/ADR_0/MOSI/MX 30 D7/SCL/MISO/TX 31 EA 32 GND 33 U1 MFRC52202HN1,151 GND

9 TVSS 10 TX1 11 TVDD 12 TX2 13 TVSS 14 AVDD 15 VMID 16 RX 17 AVSS 18 AUX1 19 AUX2 20 OSCIN 21 OSCOUT 22 IRQ 23 SDA/NSS/RX 24 D1/ADR_5 25 D2/ADR_4 26 D3/ADR_3 27 D4/ADR_2 28 D5/ADR_1/SCK/DTRQ 29 D6/ADR_0/MOSI/MX 30 D7/SCL/MISO/TX 31 EA 32 GND 33 +3V3

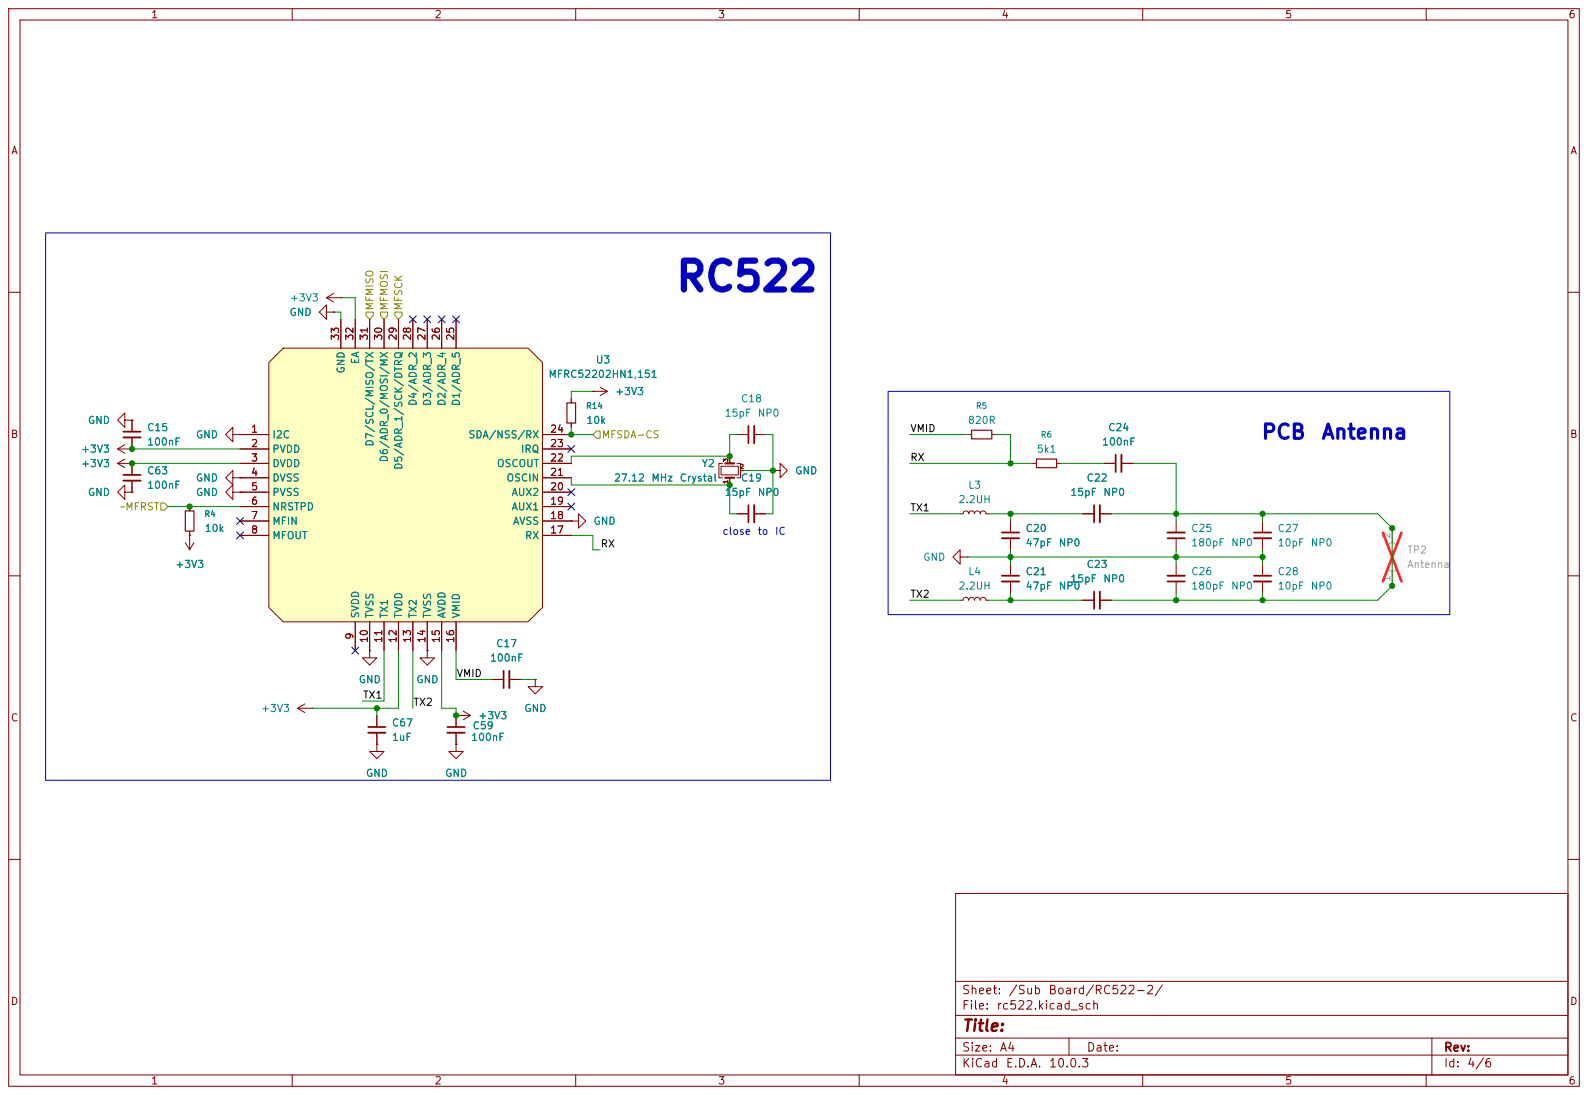
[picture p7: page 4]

9 TVSS 10 TX1 11 TVDD 12 TX2 13 TVSS 14 AVDD 15 VMID 16 RX 17 AVSS 18 AUX1 19 AUX2 20 OSCIN 21 OSCOUT 22 IRQ 23 SDA/NSS/RX 24 D1/ADR_5 25 D2/ADR_4 26 D3/ADR_3 27 D4/ADR_2 28 D5/ADR_1/SCK/DTRQ 29 D6/ADR_0/MOSI/MX 30 D7/SCL/MISO/TX 31 EA 32 GND 33 U3 MFRC52202HN1,151 GND

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

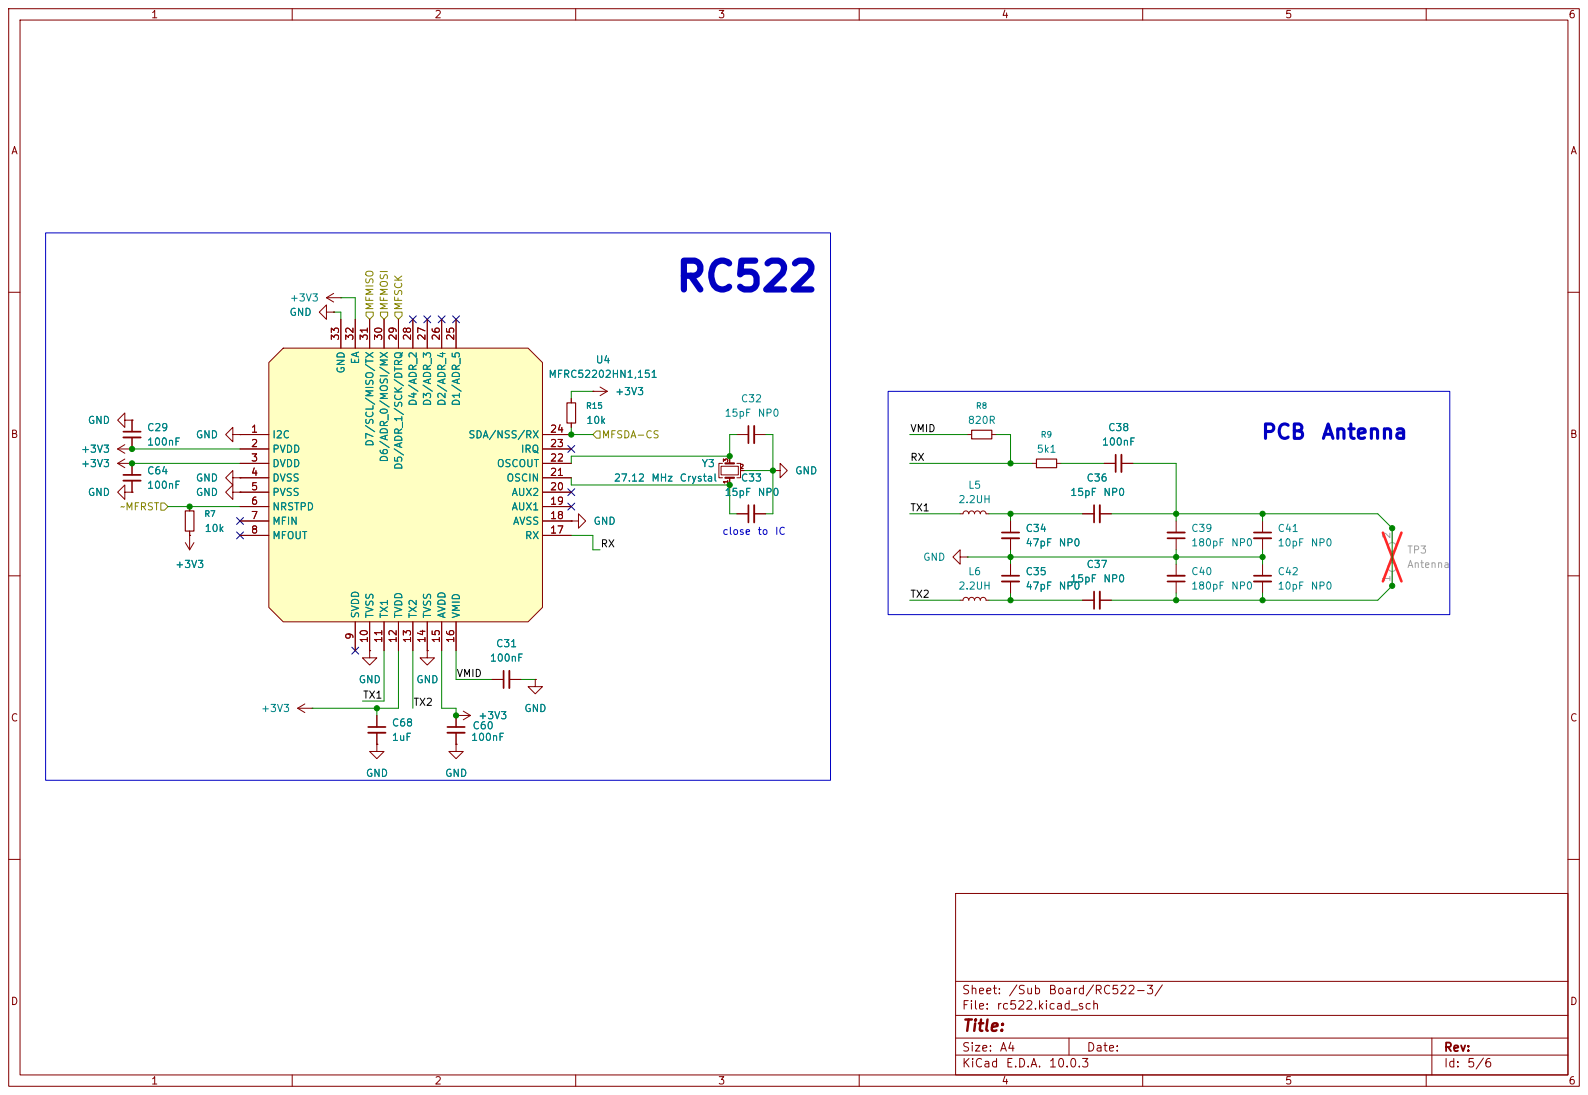
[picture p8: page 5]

9 TVSS 10 TX1 11 TVDD 12 TX2 13 TVSS 14 AVDD 15 VMID 16 RX 17 AVSS 18 AUX1 19 AUX2 20 OSCIN 21 OSCOUT 22 IRQ 23 SDA/NSS/RX 24 D1/ADR_5 25 D2/ADR_4 26 D3/ADR_3 27 D4/ADR_2 28 D5/ADR_1/SCK/DTRQ 29 D6/ADR_0/MOSI/MX 30 D7/SCL/MISO/TX 31 EA 32 GND 33 U4 MFRC52202HN1,151 GND

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

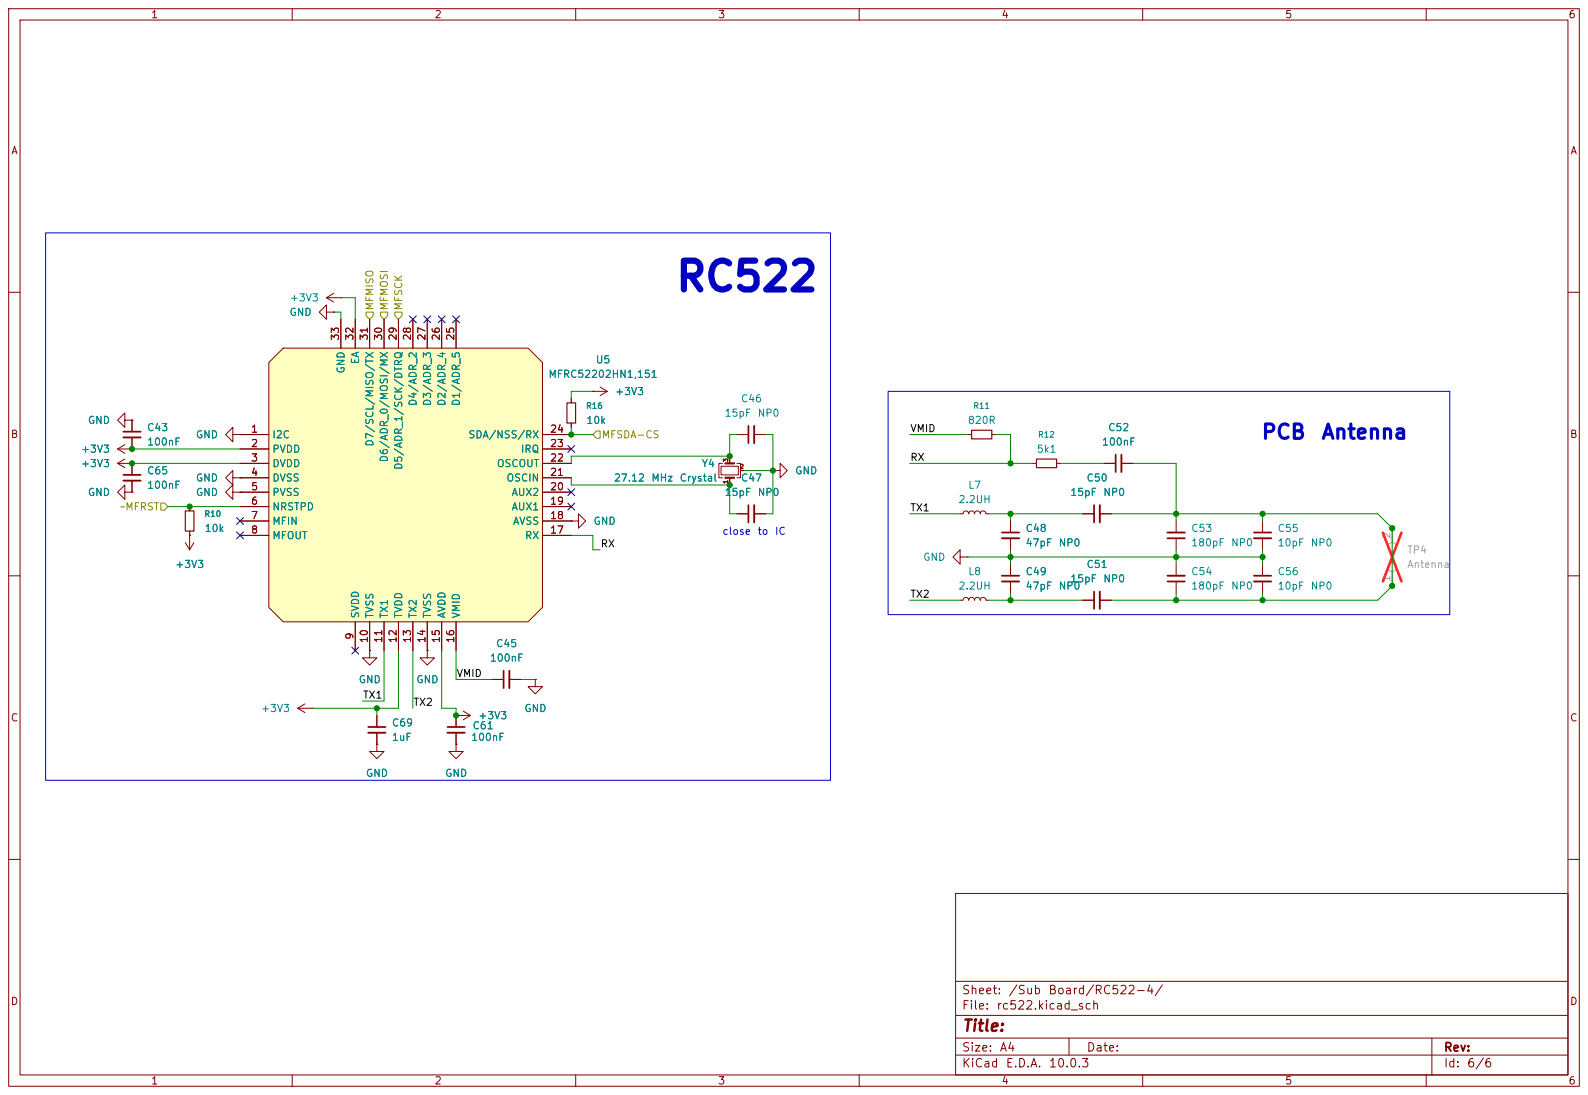
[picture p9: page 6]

9 TVSS 10 TX1 11 TVDD 12 TX2 13 TVSS 14 AVDD 15 VMID 16 RX 17 AVSS 18 AUX1 19 AUX2 20 OSCIN 21 OSCOUT 22 IRQ 23 SDA/NSS/RX 24 D1/ADR_5 25 D2/ADR_4 26 D3/ADR_3 27 D4/ADR_2 28 D5/ADR_1/SCK/DTRQ 29 D6/ADR_0/MOSI/MX 30 D7/SCL/MISO/TX 31 EA 32 GND 33 U5 MFRC52202HN1,151 GND

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

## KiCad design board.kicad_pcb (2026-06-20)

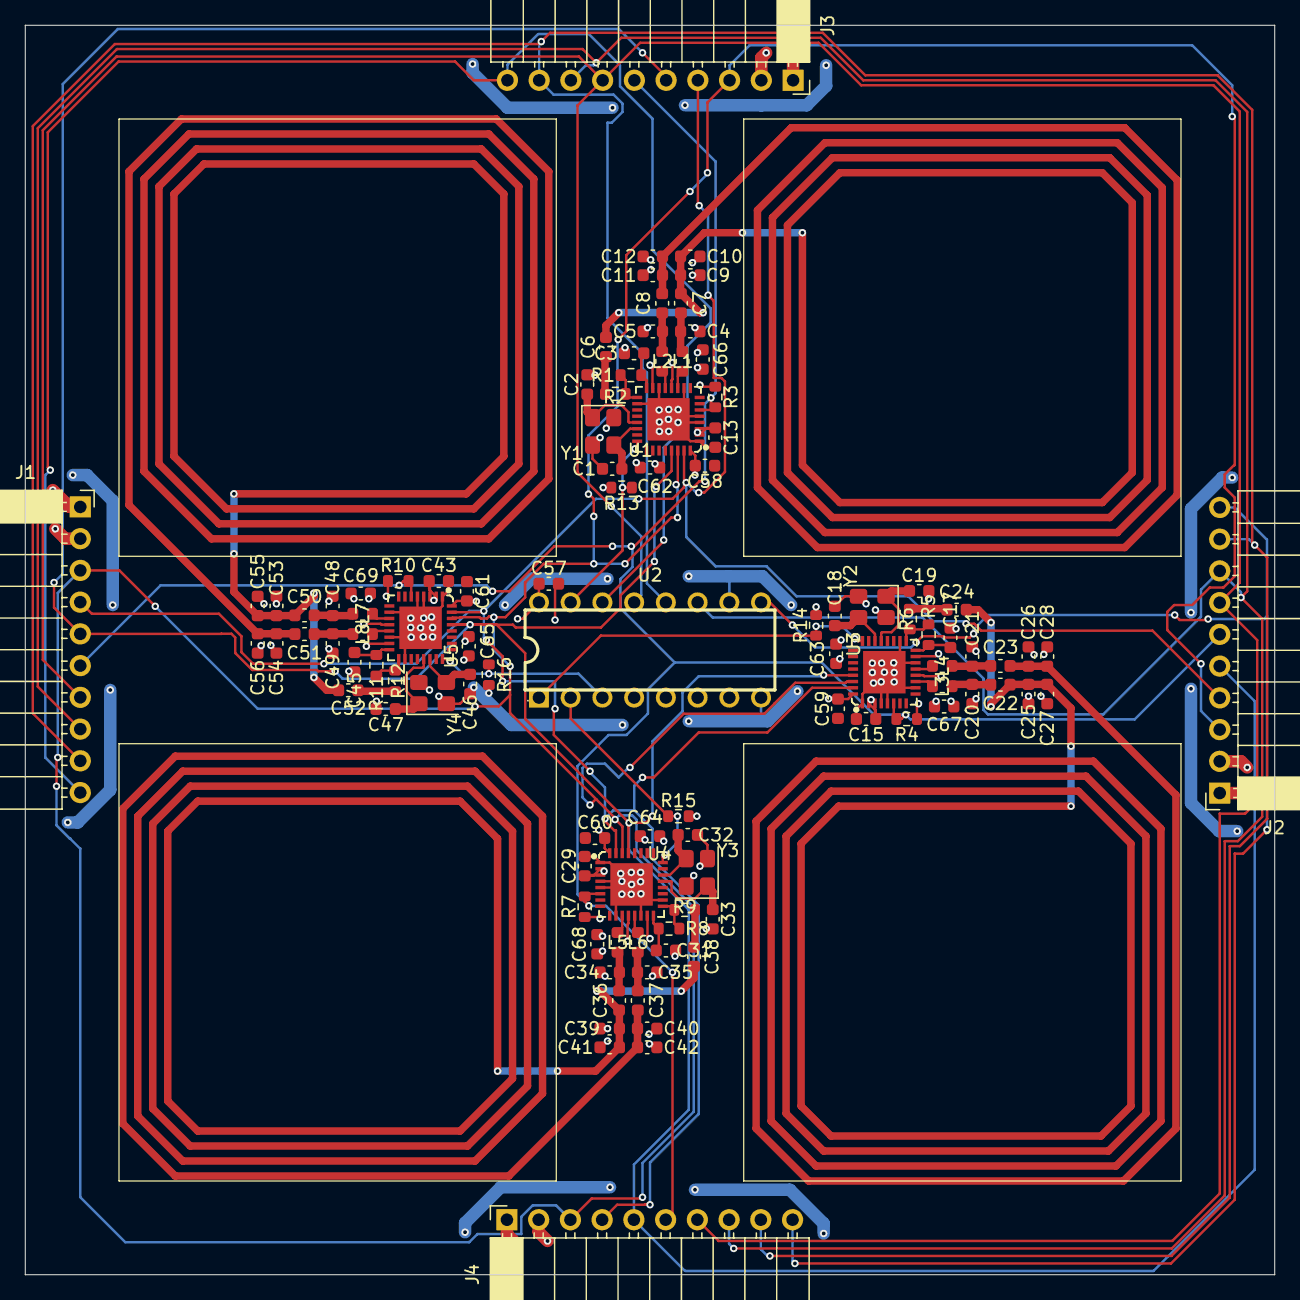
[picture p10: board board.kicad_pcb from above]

Board: 4 copper layers, 100.0 x 100.0 mm, 102 parts (0 on the bottom side), 55 nets.

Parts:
C1, C2, C18, C19, C32, C33, C46, C47: 15pF; C_0603_1608Metric
C3, C6, C13, C15, C17, C24, C29, C31, C38, C43, C45, C52, C57, C58, C59, C60, C61, C62, C63, C64, C65: 100nF; C_0603_1608Metric
C4, C5, C20, C21, C34, C35, C48, C49: 47PF; C_0603_1608Metric
C7, C8, C22, C23, C36, C37, C50, C51: 15PF; C_0603_1608Metric
C9, C11, C25, C26, C39, C40, C53, C54: 180PF; C_0603_1608Metric
C10, C12, C27, C28, C41, C42, C55, C56: 10PF; C_0603_1608Metric
C66, C67, C68, C69: 1uF; C_0603_1608Metric
J1: IN1; PinSocket_1x10_P2.54mm_Horizontal
J2: OUT1; PinSocket_1x10_P2.54mm_Horizontal
J3: IN2; PinSocket_1x10_P2.54mm_Horizontal
J4: OUT2; PinSocket_1x10_P2.54mm_Horizontal
L1, L2, L3, L4, L5, L6, L7, L8: 2.2UH; L_0603_1608Metric
R1, R5, R8, R11: 820R; R_0603_1608Metric
R2, R6, R9, R12: 5k1; R_0603_1608Metric
R3, R4, R7, R10: 10K; R_0603_1608Metric
R13, R14, R15, R16: 10k; R_0603_1608Metric
U1, U3, U4, U5: MFRC52202HN1,151; QFN-32_L5.0-W5.0-P0.50-BL-EP3.4
U2: SN74HC595N; DIP-16_L19.8-W6.5-P2.54-LS7.6-BL
Y1, Y2, Y3, Y4: 27.12 MHz Crystal; Crystal_SMD_3225-4Pin_3.2x2.5mm

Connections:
+3V3: C13.2, C15.2, C29.2, C43.2, C57.2, C58.1, C59.1, C60.1, C61.1, C62.1, C63.1, C64.1, C65.1, C66.1, C67.1, C68.1, C69.1, J1.1, J2.1, J3.1, J4.1, R3.2, R4.2, R7.2, R10.2, R13.1, R14.1, R15.1, R16.1, U1.2 (PVDD), U1.3 (DVDD), U1.12 (TVDD), U1.15 (AVDD), U1.32 (EA), U2.10 (~SRCLR), U2.16 (VCC), U3.2 (PVDD), U3.3 (DVDD), U3.12 (TVDD), U3.15 (AVDD), U3.32 (EA), U4.2 (PVDD), U4.3 (DVDD), U4.12 (TVDD), U4.15 (AVDD), U4.32 (EA), U5.2 (PVDD), U5.3 (DVDD), U5.12 (TVDD), U5.15 (AVDD), U5.32 (EA)
/Sub Board/MISO: J1.4, J2.4, J3.4, J4.4, U1.31 (D7/SCL/MISO/TX), U3.31 (D7/SCL/MISO/TX), U4.31 (D7/SCL/MISO/TX), U5.31 (D7/SCL/MISO/TX)
/Sub Board/MOSI: J1.3, J2.3, J3.3, J4.3, U1.30 (D6/ADR_0/MOSI/MX), U3.30 (D6/ADR_0/MOSI/MX), U4.30 (D6/ADR_0/MOSI/MX), U5.30 (D6/ADR_0/MOSI/MX)
/Sub Board/OE: J1.7, J2.7, J3.7, J4.7, U2.13 (~OE)
/Sub Board/RC522-1/MFSDA-CS: R13.2, U1.24 (SDA/NSS/RX), U2.15 (QA)
/Sub Board/RC522-1/RX: R1.2, R2.1, U1.17 (RX)
/Sub Board/RC522-1/TX1: L1.1, U1.11 (TX1)
/Sub Board/RC522-1/TX2: L2.1, U1.13 (TX2)
/Sub Board/RC522-1/VMID: C3.1, R1.1, U1.16 (VMID)
/Sub Board/RC522-2/MFSDA-CS: R14.2, U2.1 (QB), U3.24 (SDA/NSS/RX)
/Sub Board/RC522-2/RX: R5.2, R6.1, U3.17 (RX)
/Sub Board/RC522-2/TX1: L3.1, U3.11 (TX1)
/Sub Board/RC522-2/TX2: L4.1, U3.13 (TX2)
/Sub Board/RC522-2/VMID: C17.1, R5.1, U3.16 (VMID)
/Sub Board/RC522-3/MFSDA-CS: R15.2, U2.2 (QC), U4.24 (SDA/NSS/RX)
/Sub Board/RC522-3/RX: R8.2, R9.1, U4.17 (RX)
/Sub Board/RC522-3/TX1: L5.1, U4.11 (TX1)
/Sub Board/RC522-3/TX2: L6.1, U4.13 (TX2)
/Sub Board/RC522-3/VMID: C31.1, R8.1, U4.16 (VMID)
/Sub Board/RC522-4/MFSDA-CS: R16.2, U2.3 (QD), U5.24 (SDA/NSS/RX)
/Sub Board/RC522-4/RX: R11.2, R12.1, U5.17 (RX)
/Sub Board/RC522-4/TX1: L7.1, U5.11 (TX1)
/Sub Board/RC522-4/TX2: L8.1, U5.13 (TX2)
/Sub Board/RC522-4/VMID: C45.1, R11.1, U5.16 (VMID)
/Sub Board/RCLK: J1.9, J2.9, J3.9, J4.9, U2.12 (RCLK)
/Sub Board/RST: J1.6, J2.6, J3.6, J4.6, R3.1, R4.1, R7.1, R10.1, U1.6 (NRSTPD), U3.6 (NRSTPD), U4.6 (NRSTPD), U5.6 (NRSTPD)
/Sub Board/SCK: J1.5, J2.5, J3.5, J4.5, U1.29 (D5/ADR_1/SCK/DTRQ), U3.29 (D5/ADR_1/SCK/DTRQ), U4.29 (D5/ADR_1/SCK/DTRQ), U5.29 (D5/ADR_1/SCK/DTRQ)
/Sub Board/SER: J1.10, J3.10, U2.14 (SER)
/Sub Board/SER_OUT: J2.10, J4.10, U2.9 (QH')
/Sub Board/SRCLK: J1.8, J2.8, J3.8, J4.8, U2.11 (SRCLK)
GND: C1.2, C2.2, C3.2, C4.2, C5.1, C9.1, C10.2, C11.2, C12.1, C13.1, C15.1, C17.2, C18.2, C19.2, C20.2, C21.1, C25.1, C26.2, C27.2, C28.1, C29.1, C31.2, C32.2, C33.2, C34.2, C35.1, C39.1, C40.2, C41.2, C42.1, C43.1, C45.2, C46.2, C47.2, C48.2, C49.1, C53.1, C54.2, C55.2, C56.1, C57.1, C58.2, C59.2, C60.2, C61.2, C62.2, C63.2, C64.2, C65.2, C66.2, C67.2, C68.2, C69.2, J1.2, J2.2, J3.2, J4.2, U1.1 (I2C), U1.4 (DVSS), U1.5 (PVSS), U1.10 (TVSS), U1.14 (TVSS), U1.18 (AVSS), U1.33 (GND), U2.8 (GND), U3.1 (I2C), U3.4 (DVSS), U3.5 (PVSS), U3.10 (TVSS), U3.14 (TVSS), U3.18 (AVSS), U3.33 (GND), U4.1 (I2C), U4.4 (DVSS), U4.5 (PVSS), U4.10 (TVSS), U4.14 (TVSS), U4.18 (AVSS), U4.33 (GND), U5.1 (I2C), U5.4 (DVSS), U5.5 (PVSS), U5.10 (TVSS), U5.14 (TVSS), U5.18 (AVSS), U5.33 (GND), Y1.2 (G), Y1.4 (G), Y2.2 (G), Y2.4 (G), Y3.2 (G), Y3.4 (G), Y4.2 (G), Y4.4 (G)
unnamed: C4.1, C7.1, L1.2
unnamed: C5.2, C8.1, L2.2
unnamed: C6.1, R2.2
unnamed: C6.2, C7.2, C8.2, C9.2, C10.1, C11.1, C12.2
unnamed: C20.1, C22.1, L3.2
unnamed: C21.2, C23.1, L4.2
unnamed: C22.2, C23.2, C24.2, C25.2, C26.1, C27.1, C28.2
unnamed: C24.1, R6.2
unnamed: C34.1, C36.1, L5.2
unnamed: C35.2, C37.1, L6.2
unnamed: C36.2, C37.2, C38.2, C39.2, C40.1, C41.1, C42.2
unnamed: C38.1, R9.2
unnamed: C48.1, C50.1, L7.2
unnamed: C49.2, C51.1, L8.2
unnamed: C50.2, C51.2, C52.2, C53.2, C54.1, C55.1, C56.2
unnamed: C52.1, R12.2
unnamed: C2.1, U1.21 (OSCIN), Y1.1
unnamed: C1.1, U1.22 (OSCOUT), Y1.3
unnamed: C19.1, U3.21 (OSCIN), Y2.1
unnamed: C18.1, U3.22 (OSCOUT), Y2.3
unnamed: C33.1, U4.21 (OSCIN), Y3.1
unnamed: C32.1, U4.22 (OSCOUT), Y3.3
unnamed: C47.1, U5.21 (OSCIN), Y4.1
unnamed: C46.1, U5.22 (OSCOUT), Y4.3

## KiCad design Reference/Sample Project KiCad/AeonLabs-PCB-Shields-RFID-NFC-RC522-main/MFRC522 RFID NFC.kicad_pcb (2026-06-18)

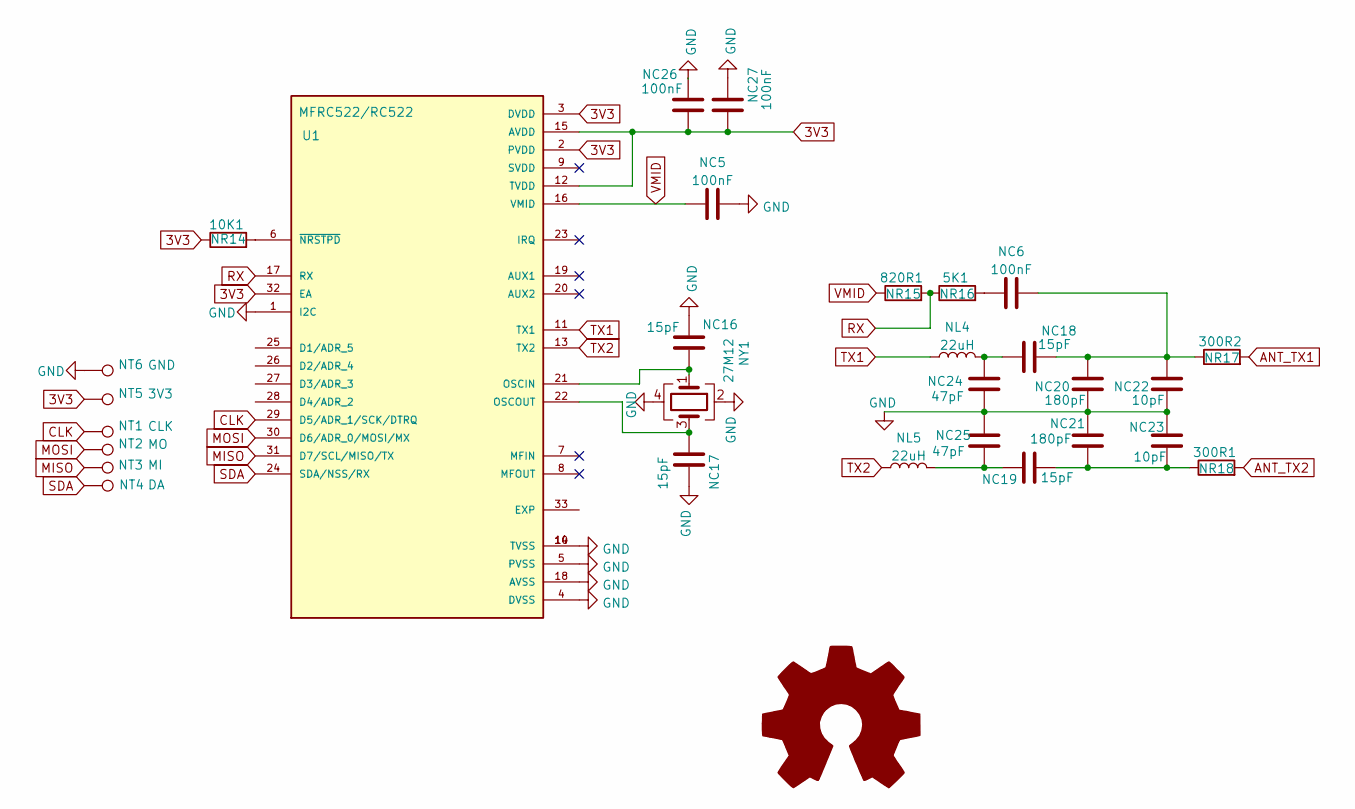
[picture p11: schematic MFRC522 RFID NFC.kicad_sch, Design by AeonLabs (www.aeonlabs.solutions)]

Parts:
5K1: NR16; R_0805_2012Metric_Pad1.20x1.40mm_HandSolder
10K1: NR14; R_0805_2012Metric_Pad1.20x1.40mm_HandSolder
300R1: NR18; R_0805_2012Metric_Pad1.20x1.40mm_HandSolder
300R2: NR17; R_0805_2012Metric_Pad1.20x1.40mm_HandSolder
820R1: NR15; R_0805_2012Metric_Pad1.20x1.40mm_HandSolder
NC5, NC6, NC26, NC27: 100nF; C_0805_2012Metric_Pad1.18x1.45mm_HandSolder
NC16, NC17, NC18, NC19: 15pF; C_0805_2012Metric_Pad1.18x1.45mm_HandSolder
NC20, NC21: 180pF; C_0805_2012Metric_Pad1.18x1.45mm_HandSolder
NC22, NC23: 10pF; C_0805_2012Metric_Pad1.18x1.45mm_HandSolder
NC24, NC25: 47pF; C_0805_2012Metric_Pad1.18x1.45mm_HandSolder
NL4, NL5: 22uH; L_0805_2012Metric_Pad1.15x1.40mm_HandSolder
NT1: CLK; TestPoint_Pad_1.0x1.0mm
NT2: MO; TestPoint_Pad_1.0x1.0mm
NT3: MI; TestPoint_Pad_1.0x1.0mm
NT4: DA; TestPoint_Pad_1.0x1.0mm
NT5: 3V3; TestPoint_Pad_1.0x1.0mm
NT6: GND; TestPoint_Pad_1.0x1.0mm
NY1: 27M12; Crystal_SMD_3225-4Pin_3.2x2.5mm_HandSoldering
U1: MFRC522/RC522; RC522 RFID NFC QFN50P500X500X100-33N; PARTREV 3.9

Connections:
3V3: 10K1.1, NC26.1, NC27.1, NT5.1, U1.2 (PVDD), U1.3 (DVDD), U1.12 (TVDD), U1.15 (AVDD), U1.32 (EA)
ANT_TX1: 300R2.2
ANT_TX2: 300R1.2
CLK: NT1.1, U1.29 (D5/ADR_1/SCK/DTRQ)
GND: NC5.2, NC16.2, NC17.2, NC20.2, NC21.1, NC22.2, NC23.1, NC24.2, NC25.1, NC26.2, NC27.2, NT6.1, NY1.2, NY1.4, U1.1 (I2C), U1.4 (DVSS), U1.5 (PVSS), U1.10 (TVSS), U1.14 (TVSS), U1.18 (AVSS)
MISO: NT3.1, U1.31 (D7/SCL/MISO/TX)
MOSI: NT2.1, U1.30 (D6/ADR_0/MOSI/MX)
unnamed: 5K1.2, NC6.1
unnamed: 10K1.2, U1.6 (~NRSTPD)
unnamed: NC16.1, NY1.1, U1.21 (OSCIN)
unnamed: NC17.1, NY1.3, U1.22 (OSCOUT)
unnamed: NC18.1, NC24.1, NL4.2
unnamed: 300R2.1, NC6.2, NC18.2, NC20.1, NC22.1
unnamed: NC19.1, NC25.2, NL5.2
unnamed: 300R1.1, NC19.2, NC21.2, NC23.2
RX: 5K1.1, 820R1.2, U1.17 (RX)
SDA: NT4.1, U1.24 (SDA/NSS/RX)
TX1: NL4.1, U1.11 (TX1)
TX2: NL5.1, U1.13 (TX2)
VMID: 820R1.1, NC5.1, U1.16 (VMID)

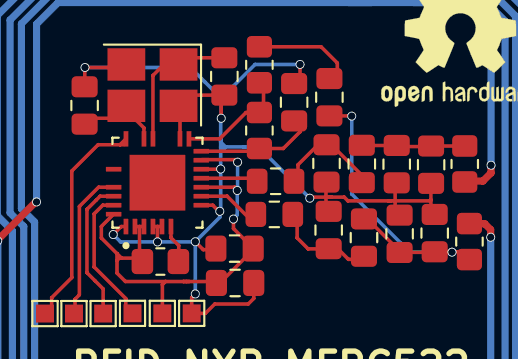
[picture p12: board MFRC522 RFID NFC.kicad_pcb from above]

Board: 2 copper layers, 29 parts (0 on the bottom side), 18 nets.

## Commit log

2026-06-10 project innit
    [board.kicad_pcb, board.kicad_sch]
2026-06-10 schematics inital complete
    [Pegoda_AN710_Antenna_Schematics_in_PCAD2006.sch, Pegoda_RM710_Schematics_in_PCAD2006.sch, RD710_BOM_NXP.xls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]
2026-06-11 PCB: one layout done, trying replication now
    [board.kicad_pcb, rc522.kicad_sch, sub-board.kicad_sch]
2026-06-12 Previous stuff and im now at a point where a single reader circuit should be ready for replecation
    [board.kicad_pcb, rc522.kicad_sch, sub-board.kicad_sch]
2026-06-12 Added non replication-relevant traces and keepout zones
    [board.kicad_pcb]
2026-06-12 Replacted layout and places replicas
    [board.kicad_pcb]
2026-06-12 added all routing (very, very ugly but theoretically done)
    [board.kicad_pcb]
2026-06-18 not sure what changed actually
    [MFRC522 RFID NFC.kicad_pcb, MFRC522 RFID NFC.kicad_sch]
2026-06-18 added BOM
    [BOM.csv]
2026-06-19 Revise README with project title and BOM details
    Updated project title and added detailed BOM information.
2026-06-19 Update pricing information for connectors and IC
2026-06-19 Add BOMs and KiCad sections to README
    Added sections for BOMs and KiCad usage instructions.
2026-06-19 added BOMs and Plot
    [BOM.csv, Chess Board BOM v2.xlsx, export_project_20260619_232850.xls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]
2026-06-19 Update chessboard PCB layout
2026-06-19 Update README with BOM information and links
    Added link to DigiKey BOM and clarified BOM details.
2026-06-20 changed pcb view settings
    [board.kicad_pcb]
2026-06-29 Add note about chess board assembly and cost
    Added a note about the chess board's structure and cost.

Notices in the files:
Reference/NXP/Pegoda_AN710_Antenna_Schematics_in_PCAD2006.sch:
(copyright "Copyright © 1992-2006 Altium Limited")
